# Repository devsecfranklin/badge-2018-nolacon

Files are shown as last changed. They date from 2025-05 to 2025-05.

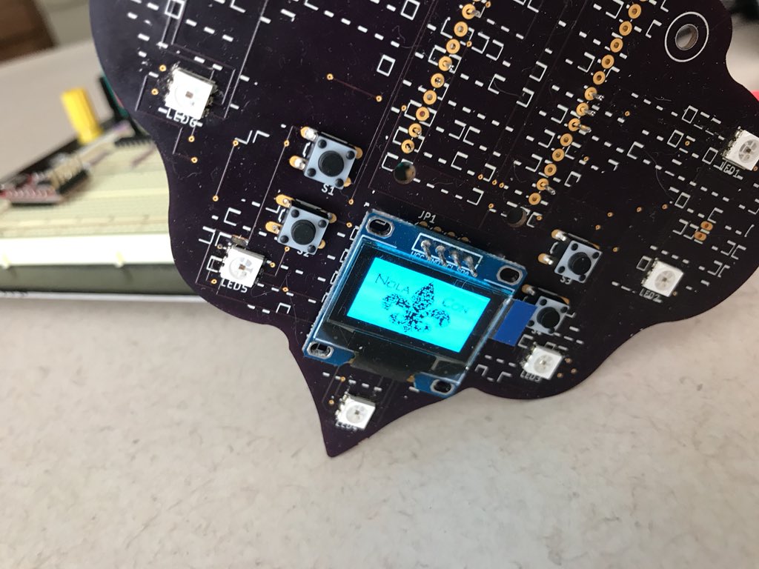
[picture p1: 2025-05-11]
images/image5.jpeg

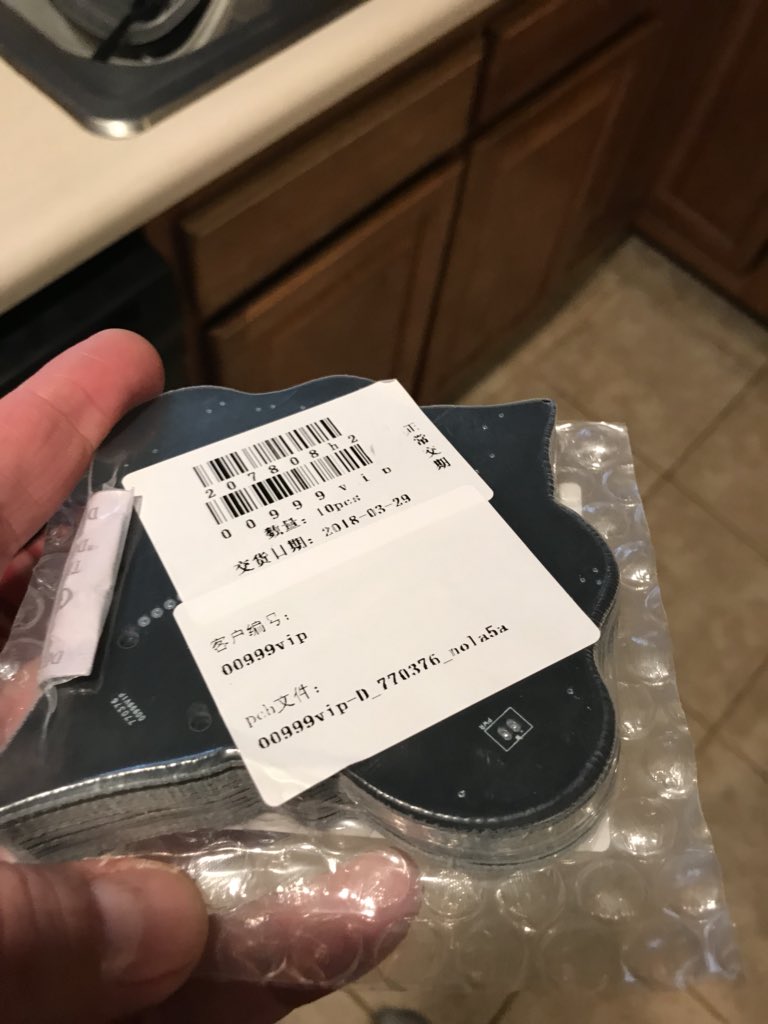
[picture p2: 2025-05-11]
images/image9.jpeg

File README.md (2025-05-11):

##  NolaCon 2018

[Check the Wiki for How To Use](https://github.com/devsecfranklin/badge-2018-nolacon/wiki)


## Created by

Будущее подпольной кибер-безопасности

- Hardware: [@thedevilsvoice](mailto:thedevilsvoice@protonmail.ch)
- Software: [@thedevilsvoice](mailto:thedevilsvoice@protonmail.ch)

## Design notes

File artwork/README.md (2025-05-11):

# Artwork

- pull bmp into fusion 360
- save bmp as dxf
- run import_dxf_polygons.ulp
  - use scale of 7.8
  - import to unused layer (like 50)
- run copy-wire-to-any-layer.ulp
  - copy from 50 to 20

## eagle

Use these settings for art import.

- import bmp 0.085 MM
- import bmp 0.0425 MM nola_layered_NEW.bmp

## Generate byte array

- [image2cpp is a simple tool to change images into byte arrays](http://javl.github.io/image2cpp/)
  (or arrays back into an images) for use with (monochrome) displays such as OLEDs on
  your Arduino or Raspberry Pi.

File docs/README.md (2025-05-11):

# Documentation

## generate

```sh
doxygen ../arduino/nola_con/Doxyfile
```

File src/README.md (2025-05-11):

sudo apt-get install python-dev
git clone git://github.com/amperka/ino.git
cd ino && sudo make install
sudo pip install ino

https://github.com/Bauerpauer/ArduinoOLEDSnake/blob/master/OLED_Snake_Game.ino
https://github.com/eholk/Arduino-Pong/blob/master/pong.ino

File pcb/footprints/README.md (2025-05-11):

# Footprints

* These are the `*.mod` and `*.kicad_mod` files used on the PCB.
* Libraries have the `*.pretty` extension.

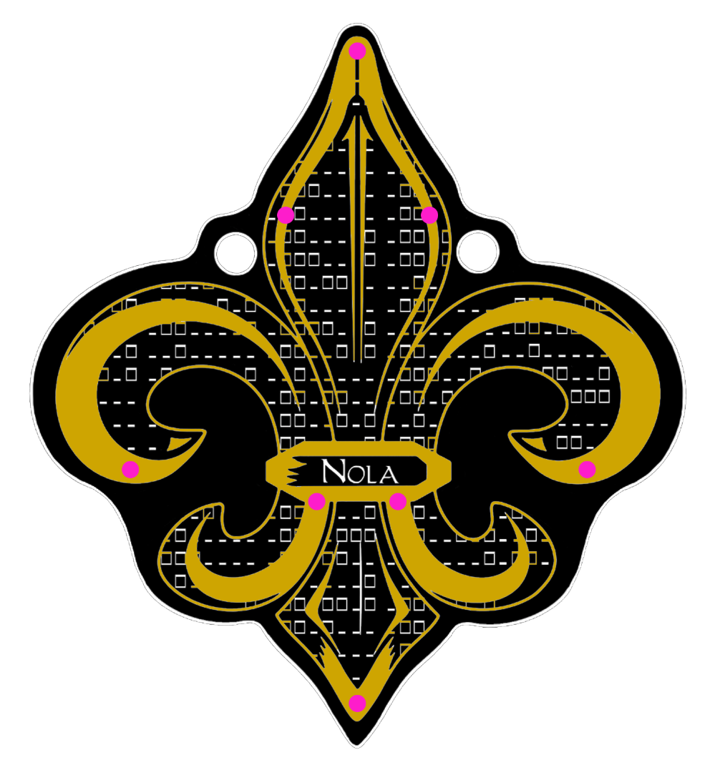
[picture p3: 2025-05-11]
artwork/led_placement.png

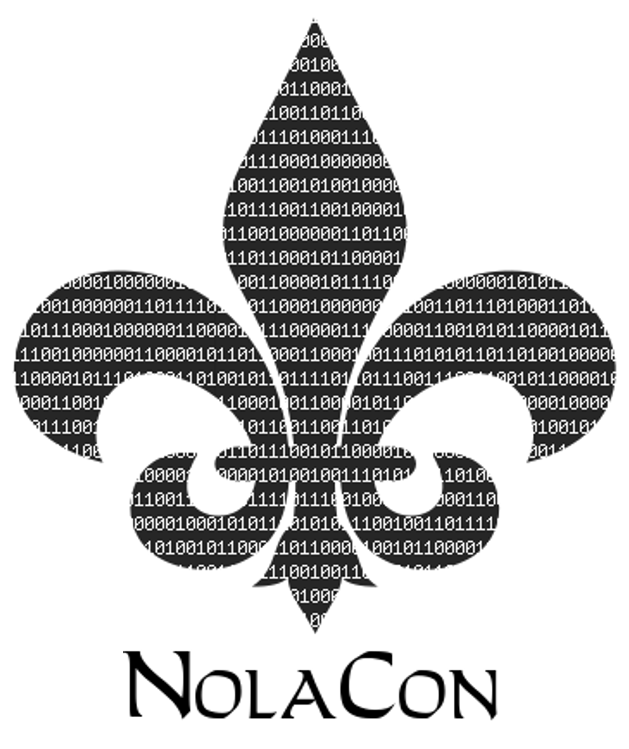
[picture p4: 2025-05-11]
artwork/fld-binary.png

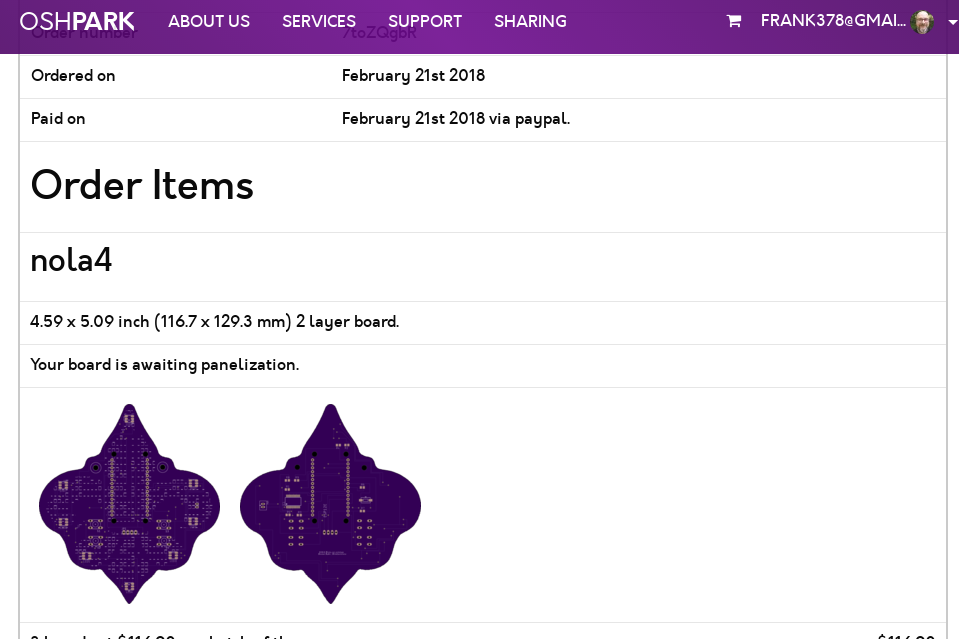
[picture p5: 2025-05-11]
artwork/Screenshot from 2018-02-20 23-40-50.png

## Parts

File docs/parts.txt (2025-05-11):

digikey

768-1007-1-ND
296-2105-5-ND
1568-1800-ND
https://www.digikey.com/product-detail/en/jst-sales-america-inc/S2B-PH-K-S(LF)(SN)/455-1719-ND/926626&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
455-1719-ND right angle JST 2 pin connector

replace the shifter with this after prototype
https://www.mouser.com/productdetail/?qs=3JMERSakebo64R9QzkDdAQ%3D%3D

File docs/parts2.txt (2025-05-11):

Partlist

Exported from nola4.brd at 3/6/18 10:01 PM

EAGLE Version 8.6.3 Copyright (c) 1988-2018 Autodesk, Inc.

Assembly variant: 

Part     Value                               Package                      Library           Position (mm)         Orientation

ESP12E   ESP12E_DEVKIT                       ESP12E_DEVKIT                ESP12E_DEVKIT     (66.83 78.865)        MR0
IC1      FT232RL                             SSOP28                       ftdichip          (90.844428125 69.801390625) MR0
JP1      OLED                                1X04                         pinhead           (66.863484375 49.80989375) R0
LED1     APA1025050                          APA102_5050                  jos-ph            (107.940109375 81.5854375) R0
LED2     APA1025050                          APA102_5050                  jos-ph            (107.7593375 56.961659375) R0
LED3     APA1025050                          APA102_5050                  jos-ph            (94.907003125 34.96619375) R0
LED4     APA1025050                          APA102_5050                  jos-ph            (66.683171875 14.930759375) R0
LED5     APA1025050                          APA102_5050                  jos-ph            (39.08078125 34.62321875) R0
LED6     APA1025050                          APA102_5050                  jos-ph            (24.1393 56.470346875) R0
LED7     APA1025050                          APA102_5050                  jos-ph            (23.9873875 80.344715625) R0
LED8     APA1025050                          APA102_5050                  jos-ph            (66.594246875 123.24236875) R0
PWR      JST-PH_2-PIN_HEADER                 JST_B2B-PH_HEADER            SRG               (110.250740625 67.293625) MR270
R1       470?                                R0805                        rcl               (94.55105625 77.54654375) MR0
R2       470?                                R0805                        rcl               (56.13835625 106.296496875) MR180
R3       10K?                                R0805                        rcl               (86.858015625 61.014075) MR0
R4       10K?                                R0805                        rcl               (61.630709375 106.241515625) MR180
R5       10K?                                R0805                        rcl               (94.050803125 61.130925) MR0
R6       10K?                                R0805                        rcl               (46.1974375 78.878584375) MR0
R7       470?                                R0805                        rcl               (46.16065625 63.638590625) MR0
R8       10K?                                R0805                        rcl               (94.525315625 83.44938125) MR0
R9       10K?                                R0805                        rcl               (88.5275125 83.43644375) MR0
S1       BACK                                B3F-10XX                     switch-omron      (44.7170875 55.075134375) R180
S2       LEFT                                B3F-10XX                     switch-omron      (44.88508125 44.3937125) R180
S3       ENTER                               B3F-10XX                     switch-omron      (88.8524875 54.887525) R180
S4       RIGHT                               B3F-10XX                     switch-omron      (89.008721875 44.382609375) R180
S5       MOMENTARY-SWITCH-SPST-SMD-6.0X3.5MM CKN10388CT-ND                SparkFun-Switches (44.027403125 70.6112875) MR0

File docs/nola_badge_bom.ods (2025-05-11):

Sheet: estimator
# of badges | 30
 |  | Part | Cost Each | Per Badge | Total | Total Count | Who | Source
 |  | APA102 | $0.45 | $3.60 | $108.00 | 240 | Franklin | https://www.adafruit.com/product/2343
 |  | OLED Screen | $5.99 | $5.99 | $179.70 | 30 | Franklin | https://www.amazon.com/gp/product/B0776T24K5
 |  | ESP8266 Chip | $9.00 | $9.00 | $270.00 | 30 | Franklin | https://www.amazon.com/HiLetgo-Internet-Development-Wireless-Micropython/dp/B010O1G1ES/
 |  | Push button Sw | $0.08 | $0.31 | $9.34 | 120 | Franklin | https://www.digikey.com/product-detail/en/te-connectivity-alcoswitch-switches/1825910-6/450-1650-ND/1632536
 |  | PCB Boards | $1.66 | $1.66 | $49.80 |  | Franklin
 |  | battery holders | $3.35 | $3.35 | $100.50 |  | Franklin | https://www.amazon.com/Gfortune-Cable-Plastic-Batteries-Holder/dp/B06XW8QC6N/
 |  | AA batteries |  |  |  |  | Rob
 |  | (custom?) lanyards with lobster hooks |  |  |  |  | Rob
 |  | Total |  |  | $717.34

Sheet: order_list
strong tape to hold battery case

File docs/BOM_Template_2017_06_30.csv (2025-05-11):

Designator | Manufacturer Part Number | Quantity
C1,C2,C3,C4,C5 | RHA0J471MCN1GS | 5
A1,A4 | 318020010 | 2
D1 | CYBLE-014008-00 | 1

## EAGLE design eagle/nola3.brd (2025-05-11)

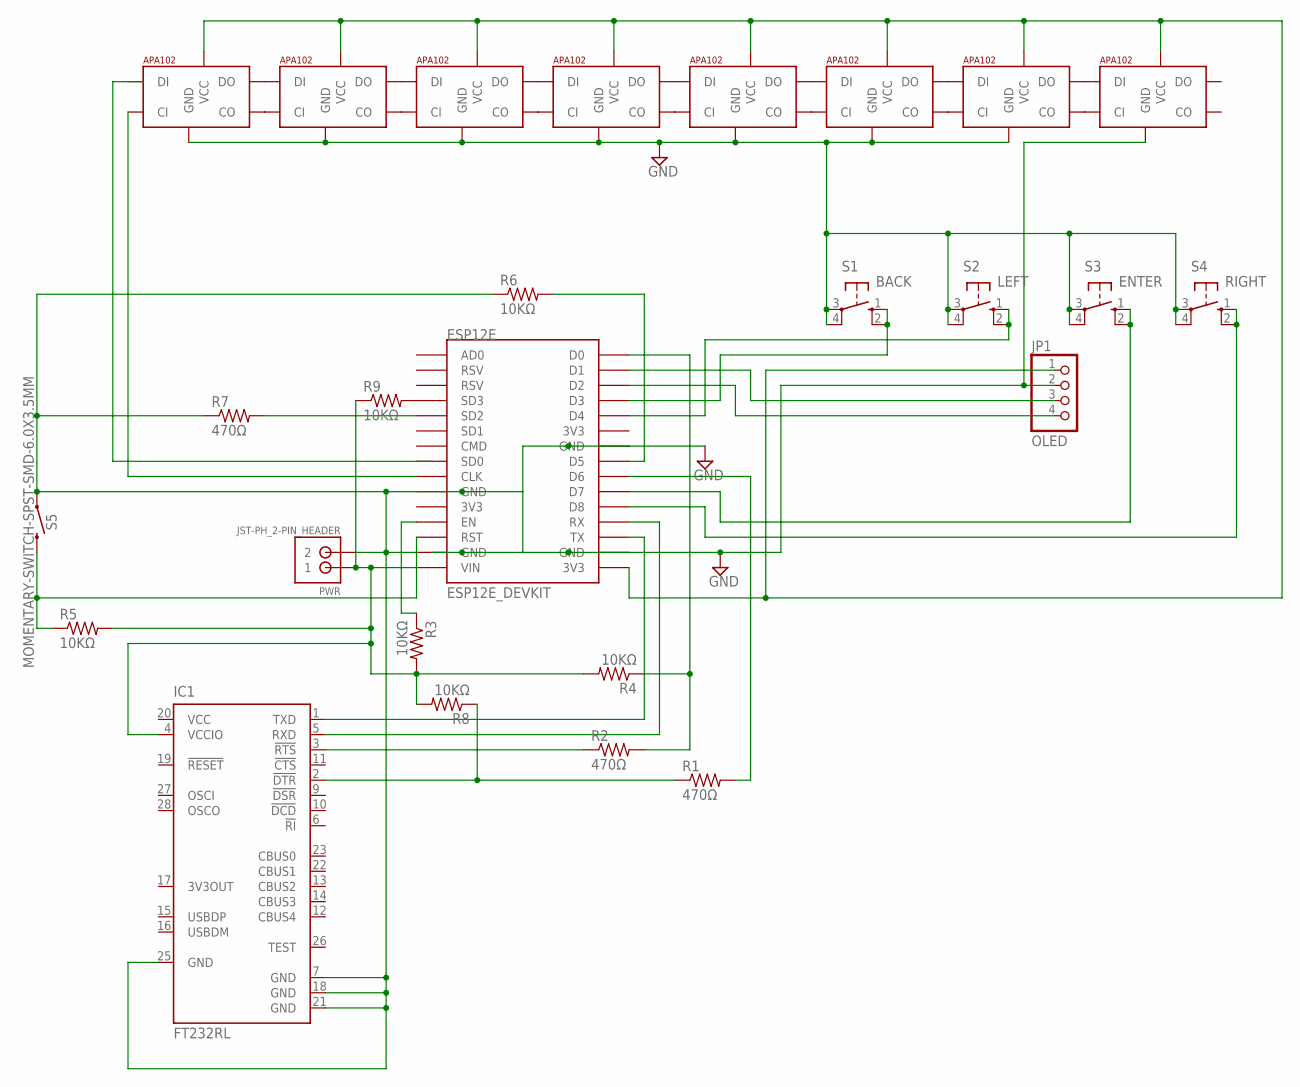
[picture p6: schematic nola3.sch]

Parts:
ESP12E: ESP12E_DEVKIT
IC1: FT232RL; SSOP28
JP1: OLED; 1X04
LED1, LED2, LED3, LED4, LED5, LED6, LED7, LED8: APA1025050; APA102_5050
PWR: JST-PH_2-PIN_HEADER; JST_B2B-PH_HEADER
R1, R2, R7: 470Ω; R0805
R3, R4, R5, R6, R8, R9: 10KΩ; R0805
S1: BACK; B3F-10XX
S2: LEFT; B3F-10XX
S3: ENTER; B3F-10XX
S4: RIGHT; B3F-10XX
S5: MOMENTARY-SWITCH-SPST-SMD-6.0X3.5MM; TACTILE_SWITCH_SMD_6.0X3.5MM

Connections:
GND: ESP12E.GND@0 (GND), ESP12E.GND@1 (GND), ESP12E.GND@2 (GND), ESP12E.GND@3 (GND), IC1.7 (GND), IC1.18 (GND), IC1.21 (GND), IC1.25 (GND), JP1.2, LED1.6 (GND), LED2.6 (GND), LED3.6 (GND), LED4.6 (GND), LED5.6 (GND), LED6.6 (GND), LED7.6 (GND), LED8.6 (GND), PWR.P2 (2), R6.1, R7.1, S1.3, S1.4 (P1), S2.3, S2.4 (P1), S3.3, S3.4 (P1), S4.3, S4.4 (P1), S5.1
unnamed: LED1.3 (DO), LED2.4 (DI)
unnamed: LED1.2 (CO), LED2.5 (CI)
unnamed: LED2.3 (DO), LED3.4 (DI)
unnamed: LED2.2 (CO), LED3.5 (CI)
unnamed: LED3.3 (DO), LED4.4 (DI)
unnamed: LED3.2 (CO), LED4.5 (CI)
unnamed: LED4.3 (DO), LED5.4 (DI)
unnamed: LED4.2 (CO), LED5.5 (CI)
unnamed: LED5.3 (DO), LED6.4 (DI)
unnamed: LED5.2 (CO), LED6.5 (CI)
unnamed: LED6.3 (DO), LED7.4 (DI)
unnamed: LED6.2 (CO), LED7.5 (CI)
unnamed: LED7.3 (DO), LED8.4 (DI)
unnamed: LED7.2 (CO), LED8.5 (CI)
unnamed: ESP12E.D1, JP1.3
unnamed: ESP12E.3V3@2 (3V3), JP1.1, LED1.1 (VCC), LED2.1 (VCC), LED3.1 (VCC), LED4.1 (VCC), LED5.1 (VCC), LED6.1 (VCC), LED7.1 (VCC), LED8.1 (VCC)
unnamed: ESP12E.D2, JP1.4
unnamed: ESP12E.D0, ESP12E.TX, IC1.1 (TXD), R2.2, R4.1
unnamed: ESP12E.SD0, LED1.4 (DI)
unnamed: ESP12E.CLK, LED1.5 (CI)
unnamed: ESP12E.D3, S1.1 (S), S1.2 (S1)
unnamed: ESP12E.D4, S2.1 (S), S2.2 (S1)
unnamed: ESP12E.D7, S3.1 (S), S3.2 (S1)
unnamed: ESP12E.D8, S4.1 (S), S4.2 (S1)
unnamed: ESP12E.EN, R3.1
unnamed: ESP12E.RX, IC1.5 (RXD)
unnamed: ESP12E.RST, R5.1, S5.2
unnamed: IC1.3 (!RTS), R2.1
unnamed: ESP12E.D6, R1.2
unnamed: IC1.2 (!DTR), R1.1, R8.1
unnamed: ESP12E.VIN, IC1.4 (VCCIO), PWR.P1 (1), R3.2, R4.2, R5.2, R8.2, R9.1
unnamed: ESP12E.SD2, R7.2
unnamed: ESP12E.D5, R6.2
unnamed: ESP12E.SD3, R9.2
VCC: IC1.20 (VCC)

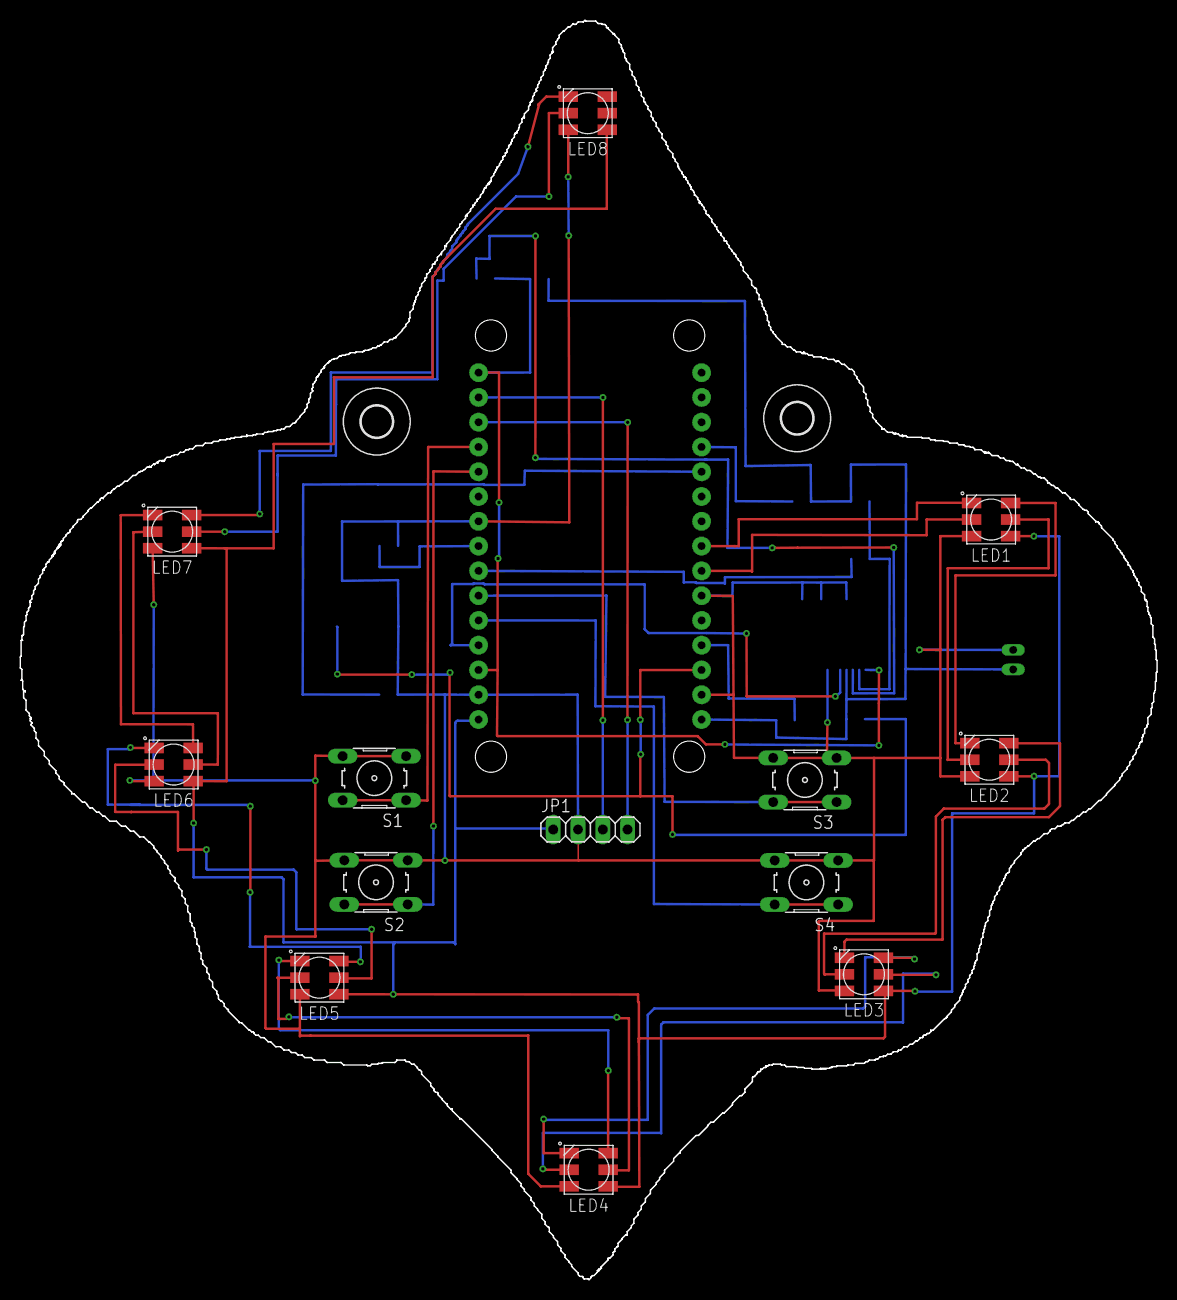
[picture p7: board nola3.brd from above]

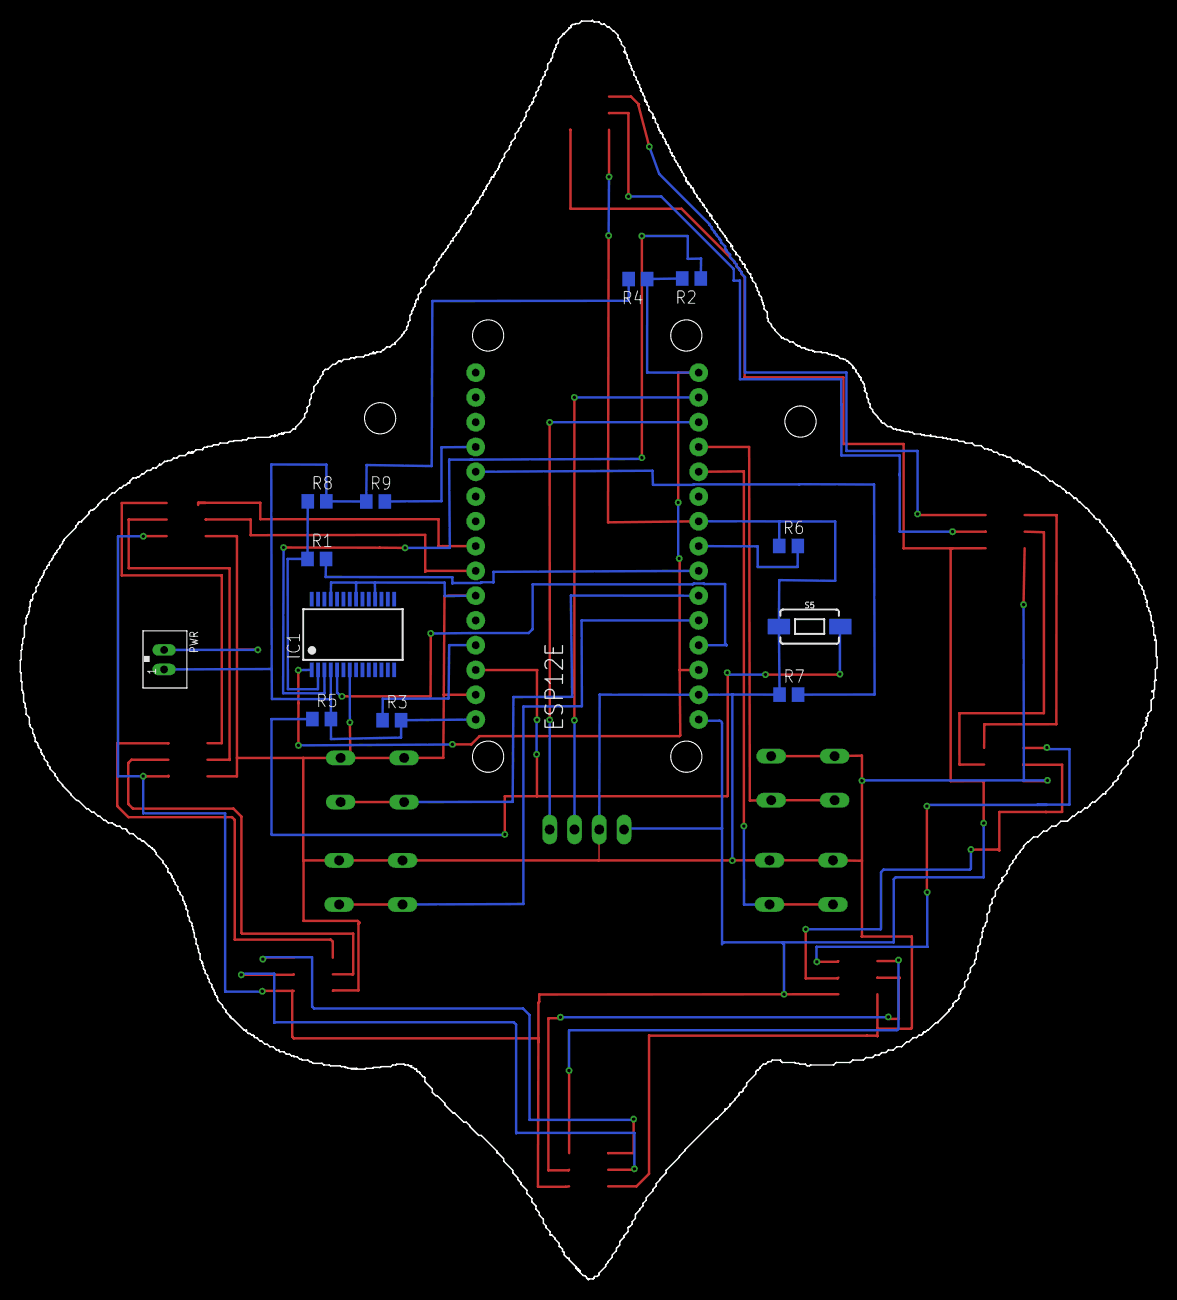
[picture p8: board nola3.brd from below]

Board: 2 copper layers, 116.5 x 129.1 mm, 28 parts (13 on the bottom side), 35 nets.

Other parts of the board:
U$1, U$2: 3,2

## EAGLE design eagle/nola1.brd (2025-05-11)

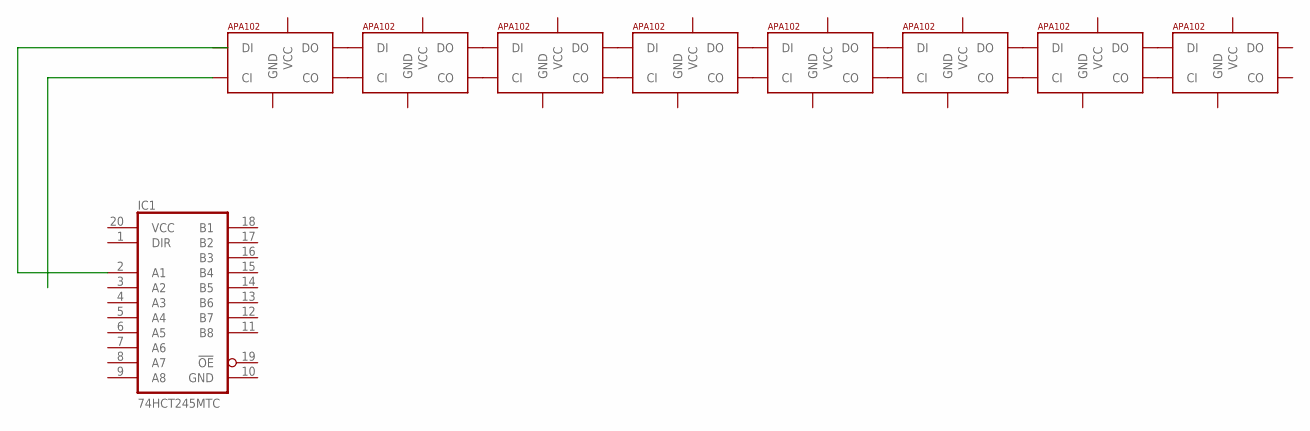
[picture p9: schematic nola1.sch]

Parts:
IC1: 74HCT245MTC; SSOP20
U$3, U$4, U$5, U$6, U$7, U$8, U$9, U$10: APA1025050; APA102_5050

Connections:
GND: IC1.10 (GND)
unnamed: U$3.3 (DO), U$4.4 (DI)
unnamed: U$3.2 (CO), U$4.5 (CI)
unnamed: U$4.3 (DO), U$5.4 (DI)
unnamed: U$4.2 (CO), U$5.5 (CI)
unnamed: U$5.3 (DO), U$6.4 (DI)
unnamed: U$5.2 (CO), U$6.5 (CI)
unnamed: U$6.3 (DO), U$7.4 (DI)
unnamed: U$6.2 (CO), U$7.5 (CI)
unnamed: U$7.3 (DO), U$8.4 (DI)
unnamed: U$7.2 (CO), U$8.5 (CI)
unnamed: U$8.3 (DO), U$9.4 (DI)
unnamed: U$8.2 (CO), U$9.5 (CI)
unnamed: U$9.3 (DO), U$10.4 (DI)
unnamed: U$9.2 (CO), U$10.5 (CI)
VCC: IC1.20 (VCC)

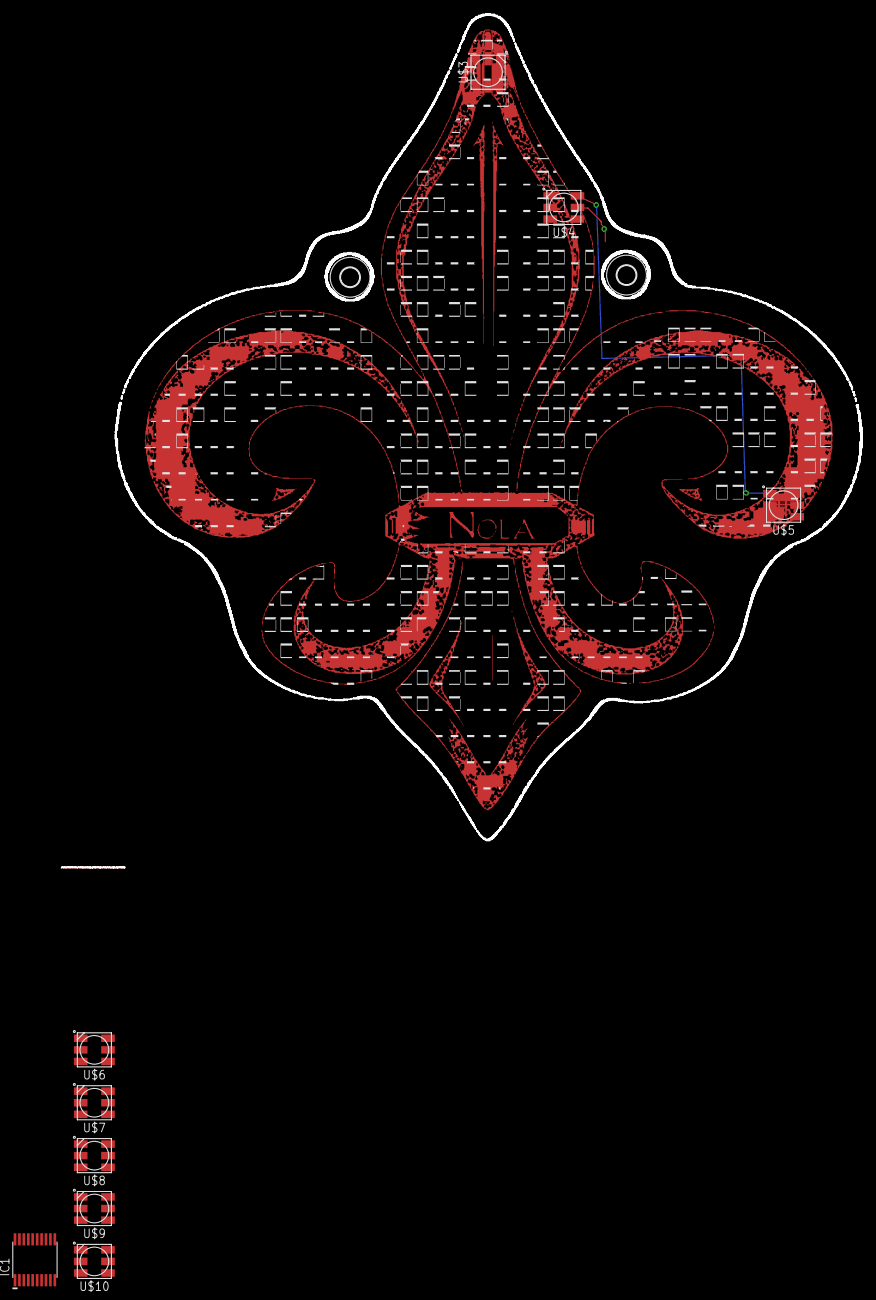
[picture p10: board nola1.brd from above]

Board: 2 copper layers, 109.6 x 121.4 mm, 11 parts (0 on the bottom side), 14 nets.

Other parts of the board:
U$1, U$2: 2,8

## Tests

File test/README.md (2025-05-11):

# test

This directory is intended for PlatformIO Unit Testing and project tests.

Unit Testing is a software testing method by which individual units of
source code, sets of one or more MCU program modules together with associated
control data, usage procedures, and operating procedures, are tested to
determine whether they are fit for use. Unit testing finds problems early
in the development cycle.

* [More information about PlatformIO Unit Testing](https://docs.platformio.org/page/plus/unit-testing.html)

## Esp32 build

### OpenBSD

* [platformio-openbsd-tool-esptool](https://github.com/lotherk/platformio-openbsd-tool-esptool)
* [ESP-IDF Visual Studio Code Extension](https://github.com/espressif/vscode-esp-idf-extension)

### Linux

The tool-chain which are the tools necessary to compile the programs:

```sh
cd ~
mkdir esp32
cd esp32
sudo apt-get install git wget make libncurses-dev flex bison gperf python python-serial
# // >> Here we download and install an x86-64 build chain (compilers)
wget https://dl.espressif.com/dl/xtensa-esp32-elf-linux64-1.22.0-61-gab8375a-5.2.0.tar.gz
tar -xvf xtensa-esp32-elf-linux64-1.22.0-61-gab8375a-5.2.0.tar.gz
sudo mv xtensa-esp32-elf /opt
export PATH=/opt/xtensa-esp32-elf/bin:$PATH
# // << End of build chain install
```

With the tools in place, what remains is the creation of the development environment
using the ESP-IDF framework:

```sh
git clone --recursive https://github.com/espressif/esp-idf.git
cd esp-idf
git submodule update --init
export IDF_PATH=~/esp32/esp-idf
```

At this point, we should have all the ingredients necessary for building an application.
The recommended way to build an application is to clone the Espressif template app
and use that as the basis for your own work.

```sh
cd ~/esp32
mkdir apps
cd apps
git clone https://github.com/espressif/esp-idf-template.git myapp
cd myapp
make menuconfig
```

We are now ready to compile our application

## Micropython

[Micropython](https://micropython.org/download/ESP32_GENERIC/)

## PlatformIO

```sh
pio run -v -t upload
```

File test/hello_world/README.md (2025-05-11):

# Hello World Example

Starts a FreeRTOS task to print "Hello World".

(See the README.md file in the upper level 'examples' directory for more information about examples.)

## How to use example

Add the following line at the end of the ~/.config/fish/config.fish file:

```sh
direnv hook fish | source
```

Install `pip` if needed.

```sh
cd /tmp && wget https://bootstrap.pypa.io/get-pip.py
python3 /tmp/get-pip.py
```

Now set up the project

```sh
. _test/bin/activate.fish
cd test/hello_world
pip3 install wheel Cython future>=0.15.2 idf-component-manager
pip3 install -r requirements.txt
/opt/esp/esp-idf/install.fish all
. /opt/esp/esp-idf/export.fish
```

Follow detailed instructions provided specifically for this example. 

Select the instructions depending on Espressif chip installed on your development board:

- [ESP32 Getting Started Guide](https://docs.espressif.com/projects/esp-idf/en/stable/get-started/index.html)
- [ESP32-S2 Getting Started Guide](https://docs.espressif.com/projects/esp-idf/en/latest/esp32s2/get-started/index.html)

## Example folder contents

The project **hello_world** contains one source file in C language [hello_world_main.c](main/hello_world_main.c). The file is located in folder [main](main).

ESP-IDF projects are built using CMake. The project build configuration is contained in `CMakeLists.txt` files that provide set of directives and instructions describing the project's source files and targets (executable, library, or both). 

Below is short explanation of remaining files in the project folder.

```
├── CMakeLists.txt
├── example_test.py            Python script used for automated example testing
├── main
│   ├── CMakeLists.txt
│   ├── component.mk           Component make file
│   └── hello_world_main.c
├── Makefile                   Makefile used by legacy GNU Make
└── README.md                  This is the file you are currently reading
```

For more information on structure and contents of ESP-IDF projects, please refer to Section [Build System](https://docs.espressif.com/projects/esp-idf/en/latest/esp32/api-guides/build-system.html) of the ESP-IDF Programming Guide.

## Troubleshooting

* Program upload failure

    * Hardware connection is not correct: run `idf.py -p PORT monitor`, and reboot your board to see if there are any output logs.
    * The baud rate for downloading is too high: lower your baud rate in the `menuconfig` menu, and try again.

## Technical support and feedback

Please use the following feedback channels:

* For technical queries, go to the [esp32.com](https://esp32.com/) forum
* For a feature request or bug report, create a [GitHub issue](https://github.com/espressif/esp-idf/issues)

We will get back to you as soon as possible.

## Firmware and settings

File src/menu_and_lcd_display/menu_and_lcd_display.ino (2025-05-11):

/*
    Copyright Giuseppe Di Cillo (www.coagula.org)
    Contact: dicillo@coagula.org
    
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
    You should have received a copy of the GNU General Public License
    along with this program.  If not, see <http://www.gnu.org/licenses/>.
*/

/*
IMPORTANT: to use the menubackend library by Alexander Brevig download it at http://www.arduino.cc/playground/uploads/Profiles/MenuBackend_1-4.zip and add the next code at line 195
	void toRoot() {
		setCurrent( &getRoot() );
	}
*/
#include "MenuBackend.h"    //MenuBackend library - copyright by Alexander Brevig
#include "Adafruit_GFX.h"
#include "Adafruit_SSD1306.h"
#include <APA102.h>

void menuUsed(MenuUseEvent);
void menuChanged(MenuChangeEvent );

/*
 int switchPin1 = D3;              
int switchPin2 = D4;
int switchPin3 = D7;
int switchPin4 = D10;
const int buttonPinLeft = 8;      // pin for the Up button
const int buttonPinRight = 9;    // pin for the Down button
const int buttonPinEsc = 10;     // pin for the Esc button
const int buttonPinEnter = 11;   // pin for the Enter button
*/

const int buttonPinLeft = D3;      // pin for the Up button
const int buttonPinRight = D4;    // pin for the Down button
const int buttonPinEsc = D7;     // pin for the Esc button
const int buttonPinEnter = D10;   // pin for the Enter button

int lastButtonPushed = 0;

int lastButtonEnterState = LOW;   // the previous reading from the Enter input pin
int lastButtonEscState = LOW;   // the previous reading from the Esc input pin
int lastButtonLeftState = LOW;   // the previous reading from the Left input pin
int lastButtonRightState = LOW;   // the previous reading from the Right input pin


long lastEnterDebounceTime = 0;  // the last time the output pin was toggled
long lastEscDebounceTime = 0;  // the last time the output pin was toggled
long lastLeftDebounceTime = 0;  // the last time the output pin was toggled
long lastRightDebounceTime = 0;  // the last time the output pin was toggled
long debounceDelay = 500;    // the debounce time

// LiquidCrystal display with:
// rs on pin 7
// rw on ground
// enable on pin 6
// d4, d5, d6, d7 on pins 5, 4, 3, 2
//LiquidCrystal lcd(2, 3, 4, 5, 6, 7);

#define OLED_RESET 2
Adafruit_SSD1306 display(OLED_RESET);

#if (SSD1306_LCDHEIGHT != 64)
#error("Height incorrect, please fix Adafruit_SSD1306.h!");
#endif

//Menu variables
MenuBackend menu = MenuBackend(menuUsed,menuChanged);

//initialize menuitems
    MenuItem menu1Item1 = MenuItem("Item1");
      MenuItem menuItem1SubItem1 = MenuItem("Item1SubItem1");
      MenuItem menuItem1SubItem2 = MenuItem("Item1SubItem2");
    MenuItem menu1Item2 = MenuItem("Item2");
      MenuItem menuItem2SubItem1 = MenuItem("Item2SubItem1");
      MenuItem menuItem2SubItem2 = MenuItem("Item2SubItem2");
      MenuItem menuItem3SubItem3 = MenuItem("Item2SubItem3");
    MenuItem menu1Item3 = MenuItem("Item3");

void setup()
{
  pinMode(buttonPinLeft, INPUT);
  pinMode(buttonPinRight, INPUT);
  pinMode(buttonPinEnter, INPUT);
  pinMode(buttonPinEsc, INPUT);
  
  
  // initialize with the I2C addr 0x3C (for the 128x32)
  display.begin(SSD1306_SWITCHCAPVCC, 0x3C);  
  display.clearDisplay();
  display.setTextSize(1);
  display.setTextColor(WHITE);

  //configure menu
  menu.getRoot().add(menu1Item1);
  menu1Item1.addRight(menu1Item2).addRight(menu1Item3);
  menu1Item1.add(menuItem1SubItem1).addRight(menuItem1SubItem2);
  menu1Item2.add(menuItem2SubItem1).addRight(menuItem2SubItem2).addRight(menuItem3SubItem3);
  menu.toRoot();

  
  //lcd.setCursor(0,0);  
  //lcd.print("www.coagula.org");
  String msg = "Press any button";
  display.setCursor(0, 0);
  display.println(msg);
  display.display();
  
}  // setup()...


void loop()
{

  readButtons();  //I splitted button reading and navigation in two procedures because 
  navigateMenus();  //in some situations I want to use the button for other purpose (eg. to change some settings)
                  
} //loop()... 


void menuChanged(MenuChangeEvent changed){
  
  MenuItem newMenuItem=changed.to; //get the destination menu
  
  //lcd.setCursor(0,1); //set the start position for lcd printing to the second row
  String msg;
  display.setCursor(0, 8);

  
  if(newMenuItem.getName()==menu.getRoot()){
    msg = "Main Menu       ";
    display.println(msg);
    display.display();
  }else if(newMenuItem.getName()=="Item1"){
    msg = "Item1           ";
    display.println(msg);
    display.display();
  }else if(newMenuItem.getName()=="Item1SubItem1"){
    msg = "Item1SubItem1";
    display.println(msg);
    display.display();
  }else if(newMenuItem.getName()=="Item1SubItem2"){
    msg = "Item1SubItem2   ";
    display.println(msg);
    display.display();
  }else if(newMenuItem.getName()=="Item2"){
    msg = "Item2           ";
    display.println(msg);
    display.display();
  }else if(newMenuItem.getName()=="Item2SubItem1"){
    msg = "Item2SubItem1   ";
    display.println(msg);
    display.display();
  }else if(newMenuItem.getName()=="Item2SubItem2"){
    msg = "Item2SubItem2   ";
    display.println(msg);
    display.display();
  }else if(newMenuItem.getName()=="Item2SubItem3"){
    msg = "Item2SubItem3   ";
    display.println(msg);
    display.display();
  }else if(newMenuItem.getName()=="Item3"){
    msg = "Item3           ";
    display.println(msg);
    display.display();
  }
}

void menuUsed(MenuUseEvent used){
  display.setCursor(0,0);  
  String msg = "You used        ";
  display.setCursor(0,8);   
  display.print(used.item.getName());
  display.display();
  delay(2000);  //delay to allow message reading
  display.setCursor(0,0);  
  display.print("www.coagula.org");
  display.display();
  menu.toRoot();  //back to Main
}

void  readButtons(){  //read buttons status
  int reading;
  int buttonEnterState=LOW;             // the current reading from the Enter input pin
  int buttonEscState=LOW;             // the current reading from the input pin
  int buttonLeftState=LOW;             // the current reading from the input pin
  int buttonRightState=LOW;             // the current reading from the input pin

  //Enter button
                  // read the state of the switch into a local variable:
                  reading = digitalRead(buttonPinEnter);

                  // check to see if you just pressed the enter button 
                  // (i.e. the input went from LOW to HIGH),  and you've waited 
                  // long enough since the last press to ignore any noise:  
                
                  // If the switch changed, due to noise or pressing:
                  if (reading != lastButtonEnterState) {
                    // reset the debouncing timer
                    lastEnterDebounceTime = millis();
                  } 
                  
                  if ((millis() - lastEnterDebounceTime) > debounceDelay) {
                    // whatever the reading is at, it's been there for longer
                    // than the debounce delay, so take it as the actual current state:
                    buttonEnterState=reading;
                    lastEnterDebounceTime=millis();
                  }
                  
                  // save the reading.  Next time through the loop,
                  // it'll be the lastButtonState:
                  lastButtonEnterState = reading;
                  

    //Esc button               
                  // read the state of the switch into a local variable:
                  reading = digitalRead(buttonPinEsc);

                  // check to see if you just pressed the Down button 
                  // (i.e. the input went from LOW to HIGH),  and you've waited 
                  // long enough since the last press to ignore any noise:  
                
                  // If the switch changed, due to noise or pressing:
                  if (reading != lastButtonEscState) {
                    // reset the debouncing timer
                    lastEscDebounceTime = millis();
                  } 
                  
                  if ((millis() - lastEscDebounceTime) > debounceDelay) {
                    // whatever the reading is at, it's been there for longer
                    // than the debounce delay, so take it as the actual current state:
                    buttonEscState = reading;
                    lastEscDebounceTime=millis();
                  }
                  
                  // save the reading.  Next time through the loop,
                  // it'll be the lastButtonState:
                  lastButtonEscState = reading; 
                  
                     
   //Down button               
                  // read the state of the switch into a local variable:
                  reading = digitalRead(buttonPinRight);

                  // check to see if you just pressed the Down button 
                  // (i.e. the input went from LOW to HIGH),  and you've waited 
                  // long enough since the last press to ignore any noise:  
                
                  // If the switch changed, due to noise or pressing:
                  if (reading != lastButtonRightState) {
                    // reset the debouncing timer
                    lastRightDebounceTime = millis();
                  } 
                  
                  if ((millis() - lastRightDebounceTime) > debounceDelay) {
                    // whatever the reading is at, it's been there for longer
                    // than the debounce delay, so take it as the actual current state:
                    buttonRightState = reading;
                   lastRightDebounceTime =millis();
                  }
                  
                  // save the reading.  Next time through the loop,
                  // it'll be the lastButtonState:
                  lastButtonRightState = reading;                  
                  
                  
    //Up button               
                  // read the state of the switch into a local variable:
                  reading = digitalRead(buttonPinLeft);

                  // check to see if you just pressed the Down button 
                  // (i.e. the input went from LOW to HIGH),  and you've waited 
                  // long enough since the last press to ignore any noise:  
                
                  // If the switch changed, due to noise or pressing:
                  if (reading != lastButtonLeftState) {
                    // reset the debouncing timer
                    lastLeftDebounceTime = millis();
                  } 
                  
                  if ((millis() - lastLeftDebounceTime) > debounceDelay) {
                    // whatever the reading is at, it's been there for longer
                    // than the debounce delay, so take it as the actual current state:
                    buttonLeftState = reading;
                    lastLeftDebounceTime=millis();;
                  }
                  
                  // save the reading.  Next time through the loop,
                  // it'll be the lastButtonState:
                  lastButtonLeftState = reading;  

                  //records which button has been pressed
                  if (buttonEnterState==HIGH){
                    lastButtonPushed=buttonPinEnter;

                  }else if(buttonEscState==HIGH){
                    lastButtonPushed=buttonPinEsc;

                  }else if(buttonRightState==HIGH){
                    lastButtonPushed=buttonPinRight;

                  }else if(buttonLeftState==HIGH){
                    lastButtonPushed=buttonPinLeft;

                  }else{
                    lastButtonPushed=0;
                  }                  
}

void navigateMenus() {
  MenuItem currentMenu=menu.getCurrent();
  
  switch (lastButtonPushed){
    case buttonPinEnter:
      if(!(currentMenu.moveDown())){  //if the current menu has a child and has been pressed enter then menu navigate to item below
        menu.use();
      }else{  //otherwise, if menu has no child and has been pressed enter the current menu is used
        menu.moveDown();
       } 
      break;
    case buttonPinEsc:
      menu.toRoot();  //back to main
      break;
    case buttonPinRight:
      menu.moveRight();
      break;      
    case buttonPinLeft:
      menu.moveLeft();
      break;      
  }
  
  lastButtonPushed=0; //reset the lastButtonPushed variable
}

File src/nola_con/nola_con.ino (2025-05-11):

/*!
 * @file nola_con.ino
    ____  _____      _    ____    _  ___     ____ ____
   |  _ \| ____|_   / \  |  _ \ _/ |/ _ \ _ / ___| ___|
   | | | |  _| (_) / _ \ | | | (_) | | | (_) |   |___ \
   | |_| | |___ _ / ___ \| |_| |_| | |_| |_| |___ ___) |
   |____/|_____(_)_/   \_\____/(_)_|\___/(_)\____|____/


   Author : @theDevilsVoice
   Date   : May 26, 2018
   Version: 0.6
*/


#include <Arduino.h>
#include <Adafruit_GFX.h>
#include <Adafruit_SSD1306.h>
#include <APA102.h>

#include "nola.h"
#include "MyLed.h"
#include "MyMenu.h"
#include "MyNetwork.h"

// Initialize instance of MyNetwork() class
MyNetwork mynetwork;
MyMenu mymenu;
MyLed myled;

//SSD1306 display(0x3c, D2, D1);
#define OLED_RESET 2
Adafruit_SSD1306 display(OLED_RESET);

#define CLR(x,y) (x&=(~(1<<y)))
#define SET(x,y) (x|=(1<<y))

// Create an object for writing to the LED strip.
APA102<dataPin, clockPin> ledStrip;

// Create a buffer for holding the colors (3 bytes per color).
rgb_color colors[ledCount];

void setup() {

  // initialize with the I2C addr 0x3C (for the 128x32)
  display.begin(SSD1306_SWITCHCAPVCC, 0x3C);
  display.setRotation(2);
  display.clearDisplay();
  display.setTextSize(1);
  display.setTextColor(WHITE);
  display.setCursor(0, 0);

  // deadlocks logo
  display.clearDisplay();
  display.drawBitmap(0, 0,  deadlocks, 128, 64, 1);
  display.display();
  delay(2000);

  // nolacon logo
  display.clearDisplay();
  display.drawBitmap(0, 0,  fdl_bmp1, 128, 64, 1);
  display.display();
  delay(2000);
  display.clearDisplay();
  display.display();

  pinMode(switchPin1, INPUT_PULLUP);
  pinMode(switchPin2, INPUT_PULLUP);
  pinMode(switchPin3, INPUT_PULLUP);
  pinMode(switchPin4, INPUT_PULLUP);

  mymenu.inv = 0;
  mymenu.page = 0;

}

void loop() {

   // check if any button is pressed
  if (digitalRead(switchPin1) == LOW) {               
    button_press("1");
  } else if (digitalRead(switchPin2) == LOW) {
    button_press("2");
  } else if (digitalRead(switchPin3) == LOW) {
    button_press("3");
  } else if (digitalRead(switchPin4) == LOW) {
    button_press("4");
  } else {
    //do nothing
  }

  show_menu();
}

void show_menu () {

  display.setTextSize(1);
  display.setCursor(0, 0);
  for(int a = 0; a < 5; a = a + 1 ){
    char *curr_item = new char[32];
    mymenu.my_menu[mymenu.page][a].toCharArray(curr_item, 32);
    if (!(curr_item == NULL) || !(*curr_item == '\0')) {
      if (mymenu.inv == a) {
        display.setTextColor(BLACK, WHITE);
        display.println(mymenu.my_menu[mymenu.page][a]);
        display.setTextColor(WHITE);
      } else {
        display.println(mymenu.my_menu[mymenu.page][a]);
      }
    }
  }
  display.display();

} // show_menu()

int button_press(String button_num) {

  display.setCursor(0, 0);
  display.clearDisplay();
  display.display();

  digitalWrite(switchPin1, HIGH);  // UP
  digitalWrite(switchPin2, HIGH);  // DOWN
  digitalWrite(switchPin3, HIGH);  // BACK
  digitalWrite(switchPin4, HIGH);  // ENTER

  int my_butt = button_num.toInt();

  // UP button pressed
  if (my_butt == 1 && mymenu.inv > 0) {
    mymenu.inv -= 1;
    return 0;
  }

  // DOWN button pressed
  if (my_butt == 2) {
    mymenu.inv++;
    return 0;
  }
  // BACK button pressed
  if (my_butt == 3 && mymenu.page > 0) {
    mymenu.page = 0;
    return 0;
  }
  // enter button pressed

  if (my_butt == 4) {

    /*
    for (int b = 0; b < 4; b = b++ ){
      mymenu.page
      mymenu.inv
    } */
    
    if (mymenu.page == 0 && mymenu.inv == 0) {
      // page 2 (bling)
      mymenu.page++;
      mymenu.inv = 0;   // set to invert first item
      return 0;
    }
    if (mymenu.page == 0 && mymenu.inv == 1) {
      // page 3 (network)
      mymenu.page = 3;
      mymenu.inv = 0;     // set to invert first item
      //mymenu.total = 1;  //match number of items in games menu
      return 0;
    }
    if (mymenu.page == 0 && mymenu.inv == 3) {
      // call the about() function
      about();
      return 0;
    }

    // ************* led pattern selection ***********
    if (mymenu.page == 1 && mymenu.inv == 0) {
      mymenu.ledpattern = 0;
      ledCallback();
      return 0;
    }
    if (mymenu.page == 1 && mymenu.inv == 1) {
      mymenu.ledpattern = 1;
      ledCallback();
      return 0;
    }
    if (mymenu.page == 1 && mymenu.inv == 2) {
      mymenu.ledpattern = 2;
      ledCallback();
      return 0;
    }
    if (mymenu.page == 1 && mymenu.inv == 3) {
      mymenu.ledpattern = 3; // gradient pattern
      ledCallback();
      return 0;
    }

    // ************* network tool selection ***********
    if (mymenu.page == 2 && mymenu.inv == 0) {
      // wireless scanner
      return 0;
    }
    // ************* network tool selection ***********
    if (mymenu.page == 2 && mymenu.inv == 1) {
      // mqtt
      return 0;
    }
    if (mymenu.page == 2 && mymenu.inv == 2) {
      // desync
      return 0;
    }
  }
} // button_press()

/*
 *  The buttons will break you out of the current LED pattern
 */

int break_butts() {
  if (digitalRead(switchPin1) == LOW) {               // check if the button is pressed
    // reset menu
    mymenu.inv == 0;
    mymenu.page == 0;
    // turn off LED pattern
    mymenu.ledpattern = 4;
    ledCallback();
    button_press("1");
    return 1;
  } else if (digitalRead(switchPin2) == LOW) {
    mymenu.inv == 0;
    mymenu.page == 0;
    mymenu.ledpattern = 4;
    ledCallback();
    button_press("2");
    return 1;
  } else if (digitalRead(switchPin3) == LOW) {
    mymenu.inv == 0;
    mymenu.page == 0;
    mymenu.ledpattern = 4;
    ledCallback();
    button_press("3");
    return 1;
  } else if (digitalRead(switchPin4) == LOW) {
    mymenu.inv == 0;
    mymenu.page == 0;
    mymenu.ledpattern = 4;
    ledCallback();
    button_press("4");
    return 1;
  } else {
    return 0;
  }

} //break_butts()

void ledCallback() {

  if (mymenu.ledpattern == 0) {
    cyberPolice();
  }

  if (mymenu.ledpattern == 1) {
    rainbow();
  }

  // send increasing white only
  if (mymenu.ledpattern == 2) {
    ytCracker();
  }

  // random solid colors
  if (mymenu.ledpattern == 3) {
    gradient();
  }
  // turn off leds
  if (mymenu.ledpattern == 4) {
    for (uint16_t i = 0; i < ledCount; i++) {
      colors[i] = myled.hsvToRgb(0, 0, 0);
    }
    ledStrip.write(colors, ledCount, 0);
  }
  
} // ledCallback()
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

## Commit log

2019-03-17 update buttons
2025-05-11 refresh the repo (#25)
    * move renovate
    * add in old files and refresh the repo
    * add images
    [BOM_Template_2017_06_30.csv, nola1.brd, nola1.sch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]

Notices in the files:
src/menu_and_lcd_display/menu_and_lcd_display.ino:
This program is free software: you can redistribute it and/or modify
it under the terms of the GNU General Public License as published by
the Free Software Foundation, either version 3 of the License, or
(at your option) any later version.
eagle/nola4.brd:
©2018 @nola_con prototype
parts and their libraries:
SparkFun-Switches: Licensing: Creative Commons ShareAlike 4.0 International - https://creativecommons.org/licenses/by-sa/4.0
